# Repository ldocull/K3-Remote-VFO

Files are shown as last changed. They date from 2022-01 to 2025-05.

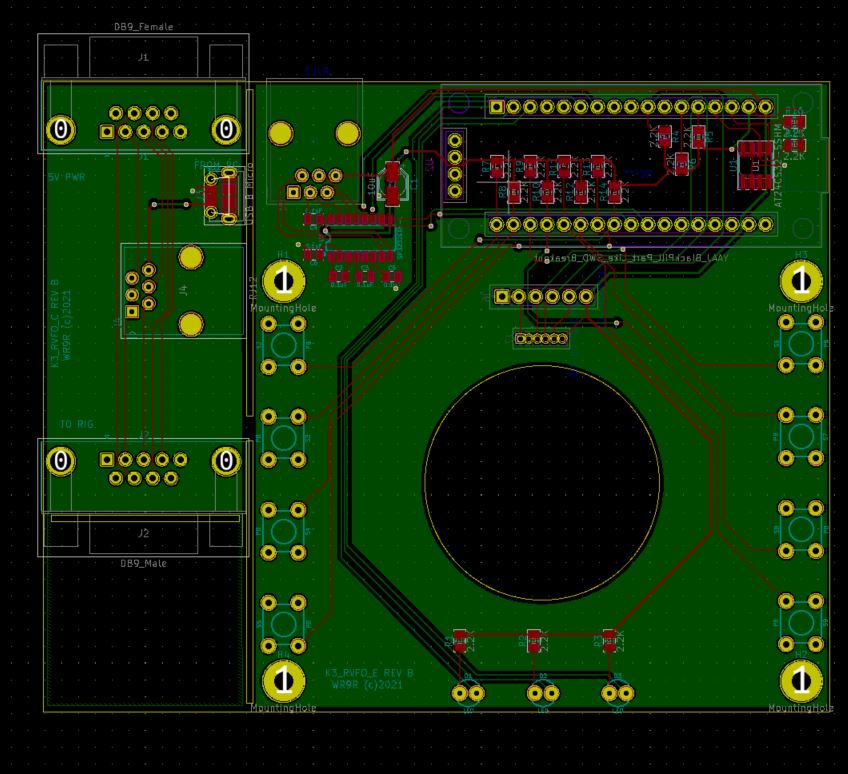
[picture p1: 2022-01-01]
PCBtop.JPG

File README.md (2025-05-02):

# K3-Remote-VFO
Remote VFO and Button Interface for Elecraft, Kenwood and other radio transceivers

## Introduction
The system is comprised of two pieces
 - A Remote Controls Unit
 - A Connector Interface to the Rig 
 
Main Remote Control Unit
Connector Interface

The Connector Interface goes between the control PC and the Rig using classic RS-232. This system is not currently set up to support modern USB interfaces. The main Remote control is tethered to the Connector Interface using a RJ12 (6P/6J) straight-through cable.  Power (5VDC) is supplied to the device from a USB port or power supply to the Connector Interface via a micro-USB jack.

## About the Design Data

The Mechanics were designed in Fusion 360, A full step-assembly is in the repo which could be pulled into any modern CAD package for alteration.   

The construction is plastic. The case frame was FDM printed from PLA, and the top/bottom were laser cut from 
0.08" acrylic. The main-dial and keycaps were SLA (resin) printed on an [Elegoo Mars](https://www.elegoo.com/collections/3d-printing/products/elegoo-mars-3-lcd-3d-printer) printer.

The Electronics were designed in KiCAD. KiCAD is free and easy to use, so this should be a good start for further work. I used [JLCPCB](https://jlcpcb.com/) to manufacture the PCBs.

PCB Setup

The Software is Arduino-based and runs on a [STM32F103C8 BlackPill](https://hobbycomponents.com/st-micro-electronics/960-stm32f103-black-pill-development-board). The project is in Visual Studio Code, and PlatformIO which are currently both free tools.  The Maple bootloader was installed to make the development quick and easy and is included in the repo.

## Updating Encoder and Key Definitions

The keys are assigned text-macros which are stored in non-volatile memory on the Remote unit. The encoder-wheel is handled the same way. The wheel can be pressed and therefore the operation has been divided into four "speeds" (as is indicated by the LEDs below the wheel.)  In the case of the encoder, the macros are also divided into four sets up ***"up"*** and ***"down"*** movements and the text contents are transmitted on each pulse of the wheel.

The default baud rate is ***38400*** and the Remote can be updated in-situ using a terminal emulator such as [RealTerm](https://realterm.sourceforge.io/).   

The following text could be uploaded to the remote.  `'$$$'` is used to mark the beginning of the upload, and `'&&&'` is used to end the upload.  Note that the macros are defined as ```<Kx> text message </K>'``` and `<Ex> text message </E>`. 

> (*Note the messages defined below are for the Elecraft K3.)*

```
$$$			// 3 dollar start of file

<K0>SWT11;</K>  //  A/B  menus stuff here...
<K1>SWT13;</K>  // A->B
<K2>SWT42;</K>  // SPOT

<K3>SWT29;</K>  // XFILT

<K4>SWT21;</K>  // M1-M2
<K5>SWT31;</K>  
<K6>SWT35;</K>  
<K7>SWT39;</K>  

<E0>UP4;</E>    // encoder modes here 0-3, increment/decrement
<E1>DN4;</E>    

<E2>UP8;</E>    
<E3>DN8;</E>    

<E4>UP1;</E>    
<E5>DN1;</E>    

<E6>UP0;</E>    
<E7>DN0;</E>	// end of file is ampersand

&&&
```

### Enjoy, 73,  de WR9R

___
Let us know that this work has been helpful to you.  Any proceeds will be used to offset expenses and further the art. 


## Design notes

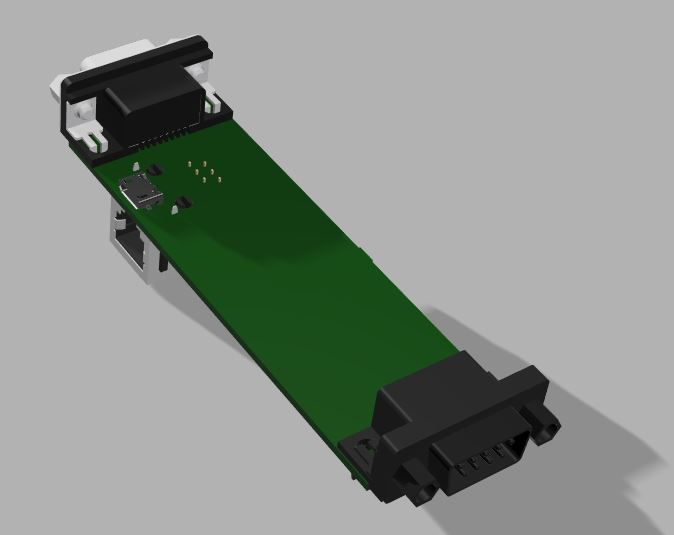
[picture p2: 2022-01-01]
Connector.JPG

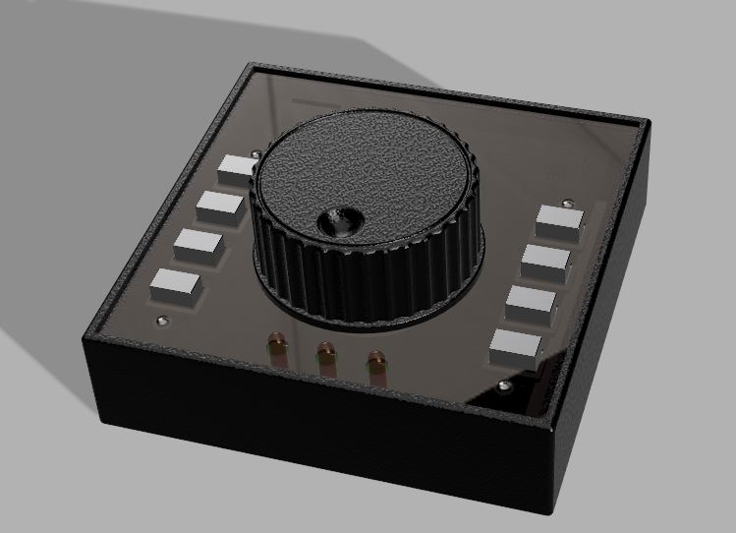
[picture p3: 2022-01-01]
Remote.JPG

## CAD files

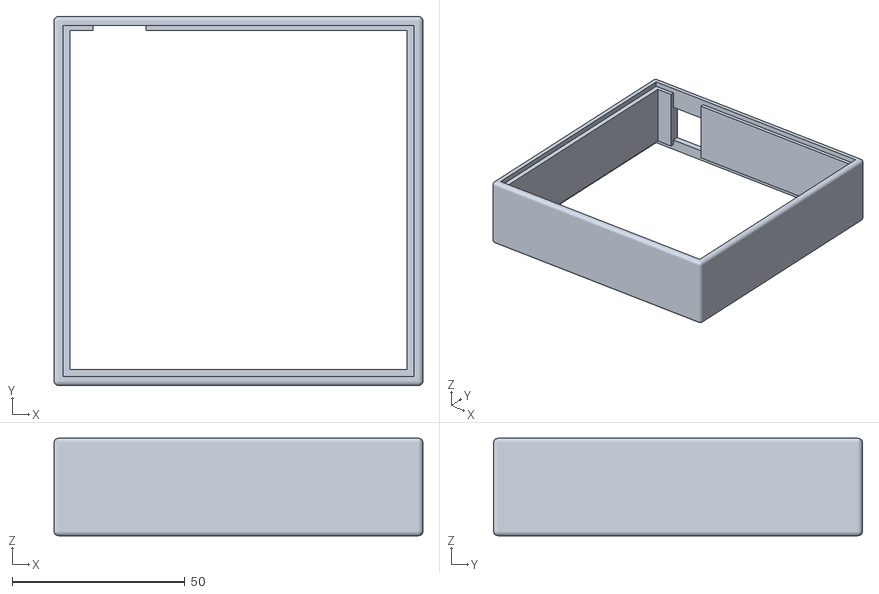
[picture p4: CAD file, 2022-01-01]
3D_Print_Files/Frame.stl
106.7 x 106.7 x 28.2

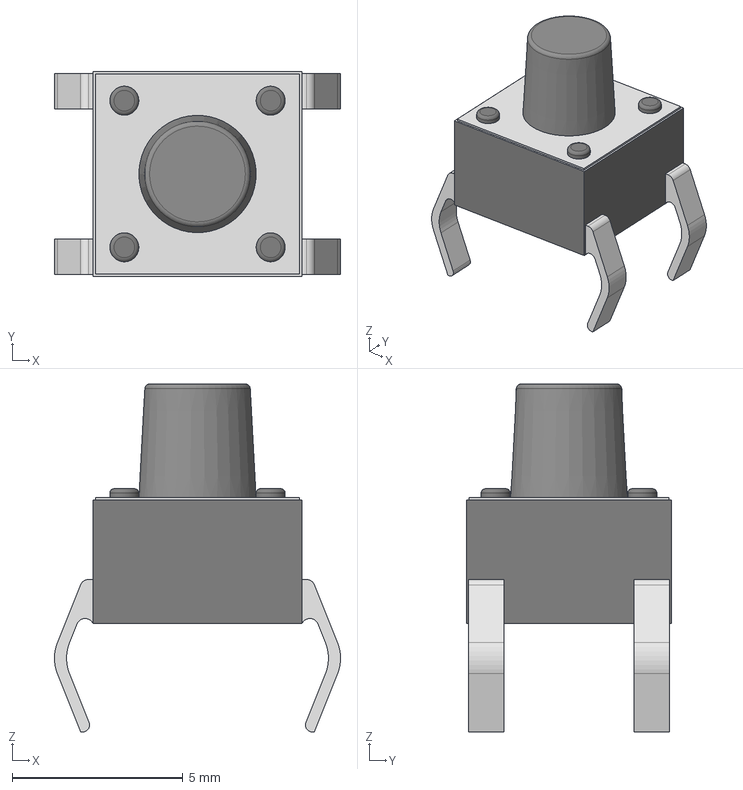
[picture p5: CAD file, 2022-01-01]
Electrical/K3_RVFO-KiCAD/Tactal Switch -Thru (6mmx 6mmx7.0mm).stp
8.37 x 5.99 x 10.2 mm

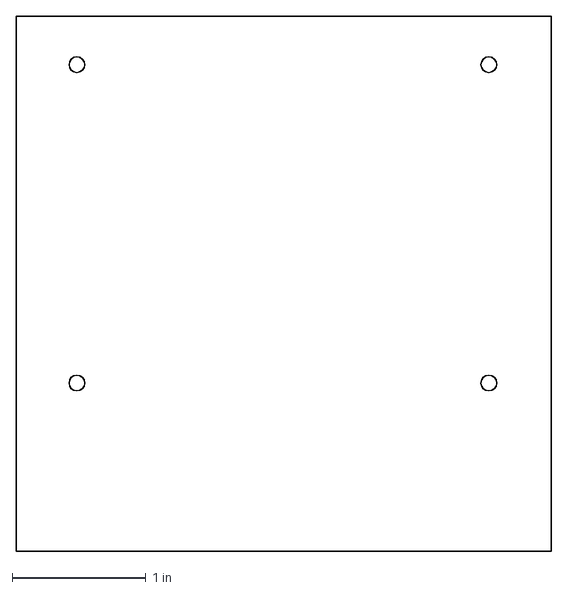
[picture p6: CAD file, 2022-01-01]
Laser_Cut_Files/BackPlate.dxf
4.00 x 4.00 in

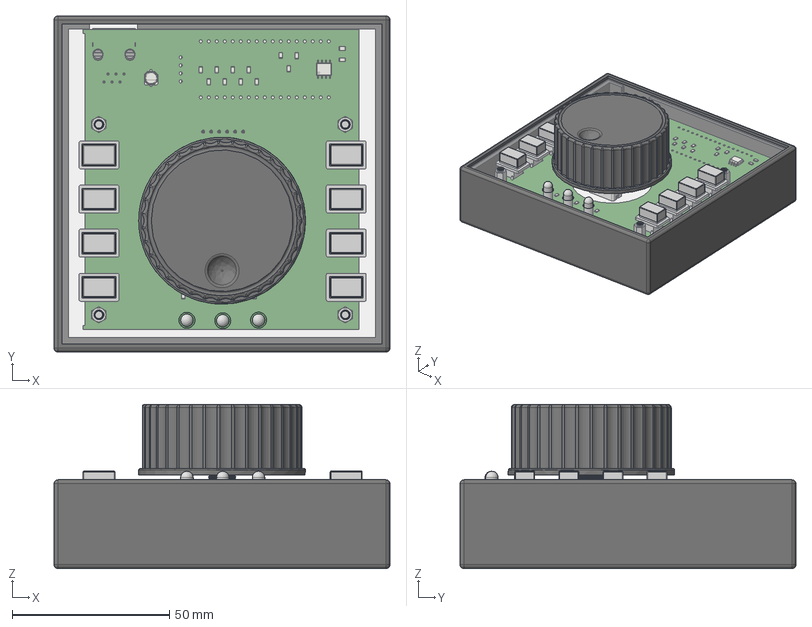
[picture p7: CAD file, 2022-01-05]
Mechanical/FreeCAD/WR9R_K3_VFO.FCStd
106.7 x 106.7 x 52.1 mm
LED
LED001
LED002
c-5555140-1-e-3d v1
KeyCap v3
Tactal Switch -Thru (6mmx 6mmx7.0mm) v1
Tactal Switch -Thru (6mmx 6mmx7.0mm) v002
KeyCap v004
Tactal Switch -Thru (6mmx 6mmx7.0mm) v003
KeyCap v005
Tactal Switch -Thru (6mmx 6mmx7.0mm) v004
KeyCap v006
KeyCap v007
Tactal Switch -Thru (6mmx 6mmx7.0mm) v005
KeyCap v008
Tactal Switch -Thru (6mmx 6mmx7.0mm) v006
Tactal Switch -Thru (6mmx 6mmx7.0mm) v007
KeyCap v009
Tactal Switch -Thru (6mmx 6mmx7.0mm) v008
KeyCap v010
NT1Knob v5
CUI_DEVICES_C14N32P-C3 v1
93655A005_Male-Female Threaded Hex Standoff
92080A012_Zinc-Plated Brass Female Threaded Hex Standoff
92080A012_Zinc-Plated Brass Female Threaded Hex Standoff001
93655A005_Male-Female Threaded Hex Standoff001
93655A005_Male-Female Threaded Hex Standoff002
93655A005_Male-Female Threaded Hex Standoff003
92080A012_Zinc-Plated Brass Female Threaded Hex Standoff002
92080A012_Zinc-Plated Brass Female Threaded Hex Standoff003
FacePlate
BackPlate
Frame

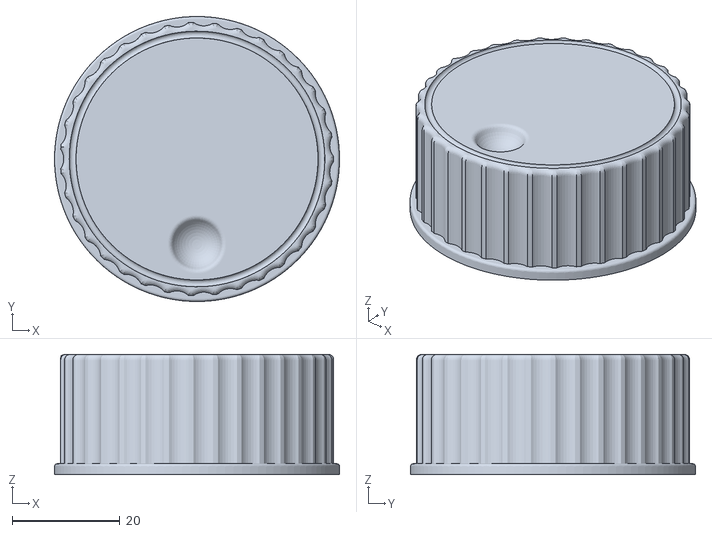
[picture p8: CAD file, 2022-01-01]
3D_Print_Files/Dial.stl
53.0 x 53.0 x 22.4

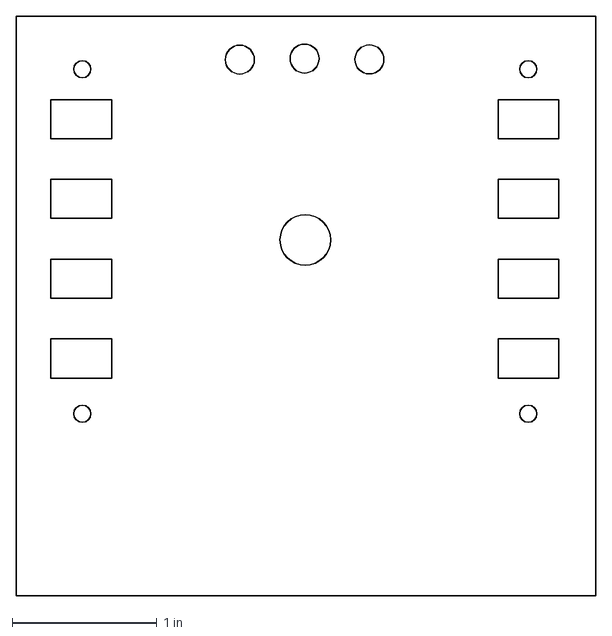
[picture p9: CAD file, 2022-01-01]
Laser_Cut_Files/FacePlate.dxf
4.00 x 4.00 in

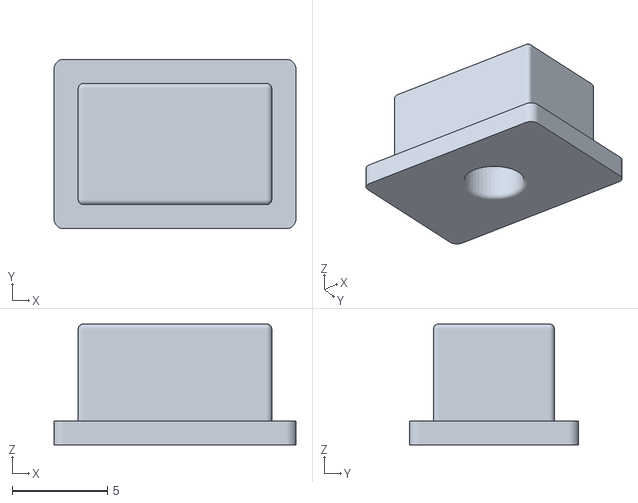
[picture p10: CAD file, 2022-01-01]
3D_Print_Files/ButtonCap.stl
12.7 x 8.89 x 6.35

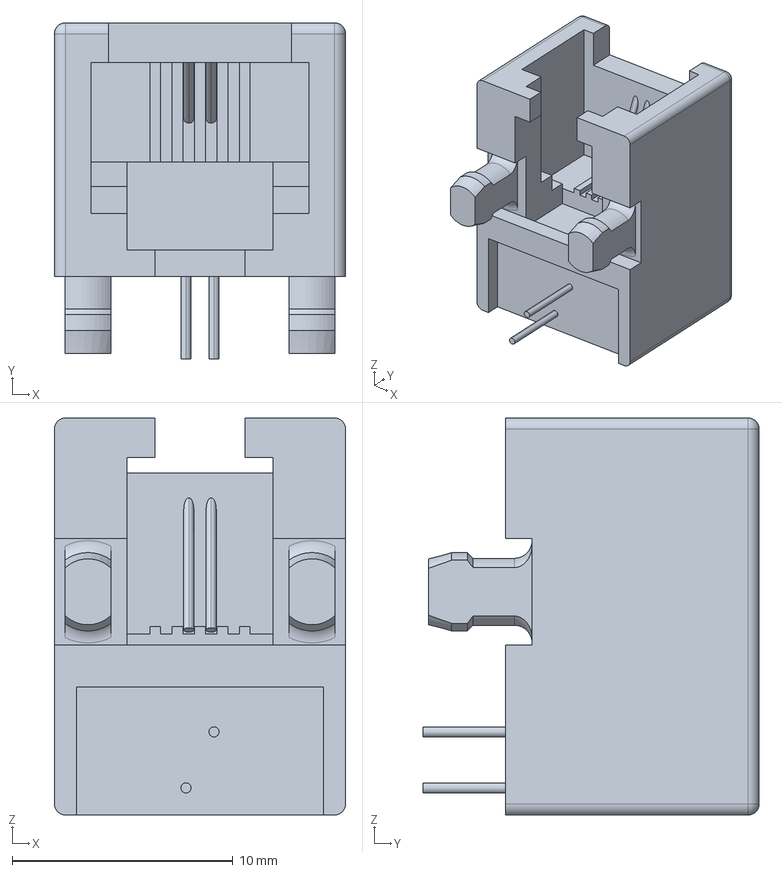
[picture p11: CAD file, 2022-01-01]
Electrical/K3_RVFO-KiCAD/54601-906001WPLFc.stp
13.2 x 15.2 x 18.0 mm

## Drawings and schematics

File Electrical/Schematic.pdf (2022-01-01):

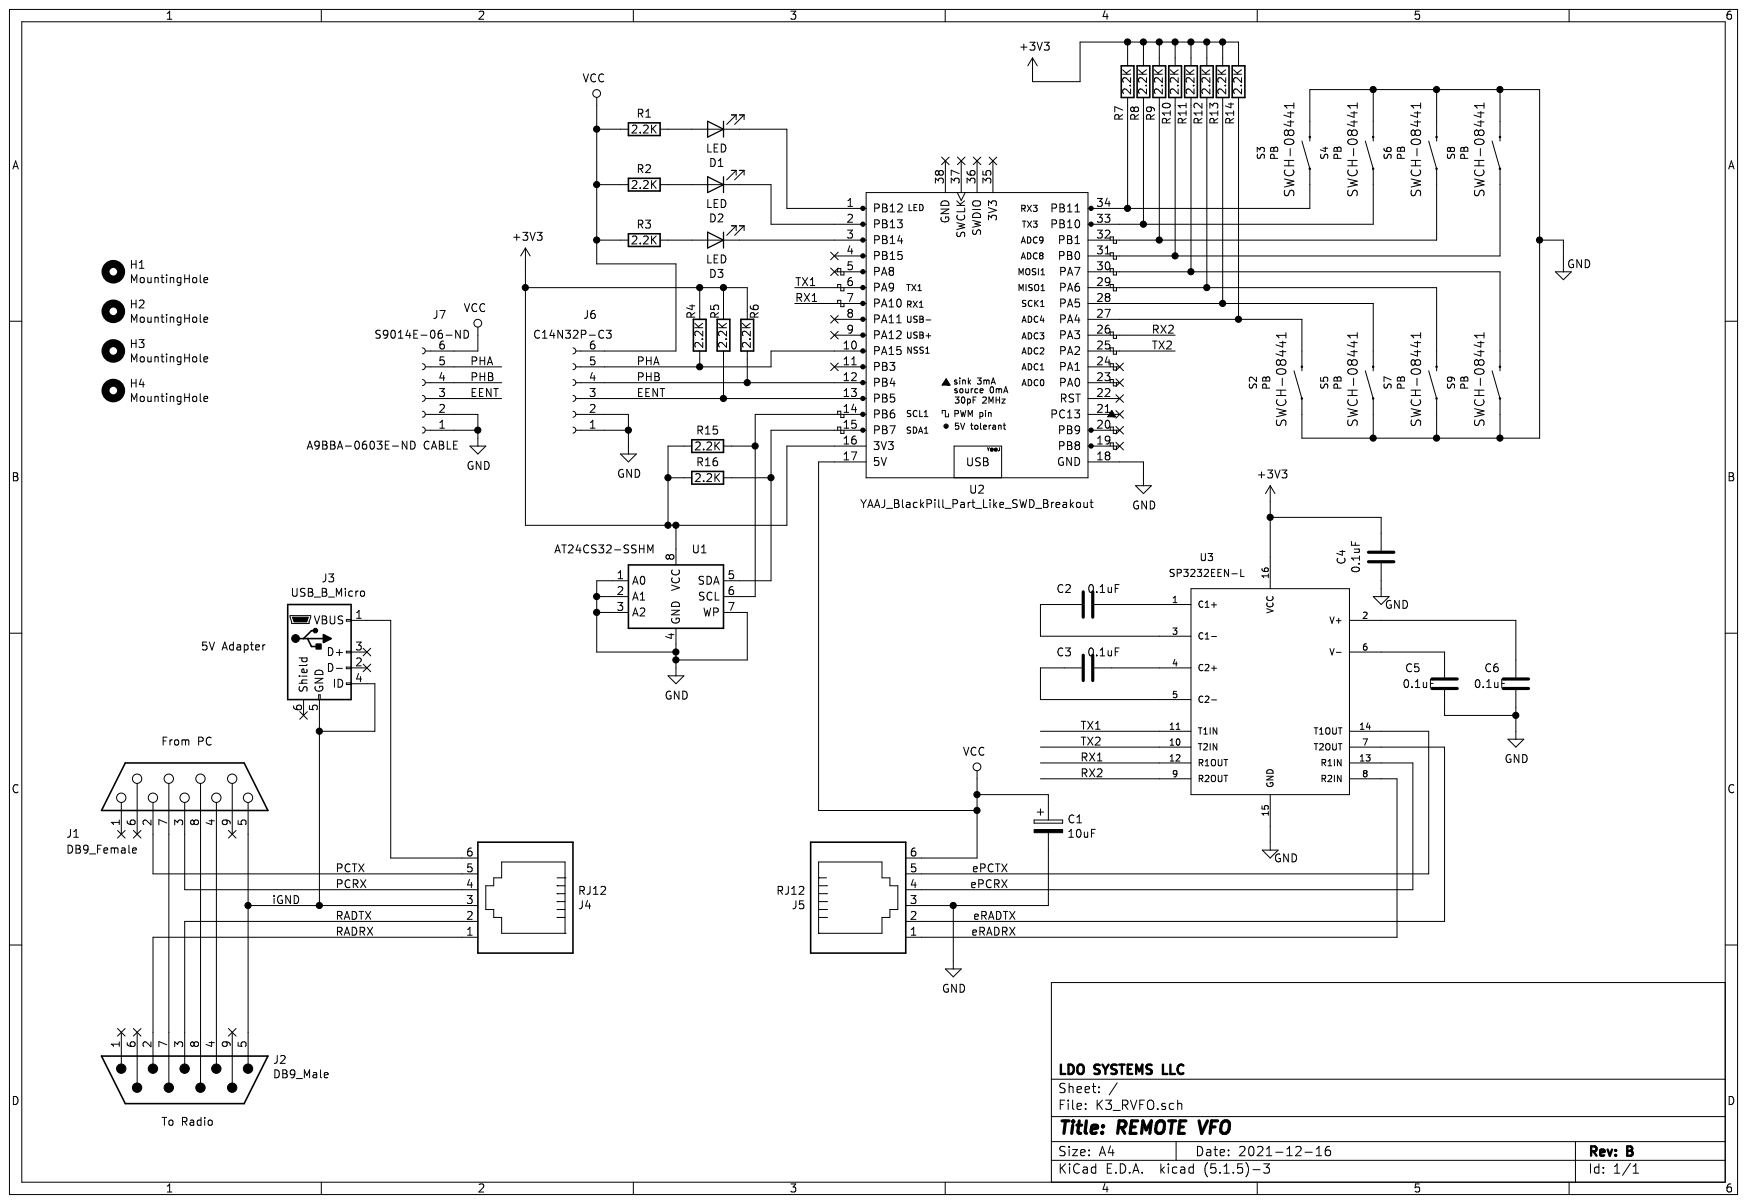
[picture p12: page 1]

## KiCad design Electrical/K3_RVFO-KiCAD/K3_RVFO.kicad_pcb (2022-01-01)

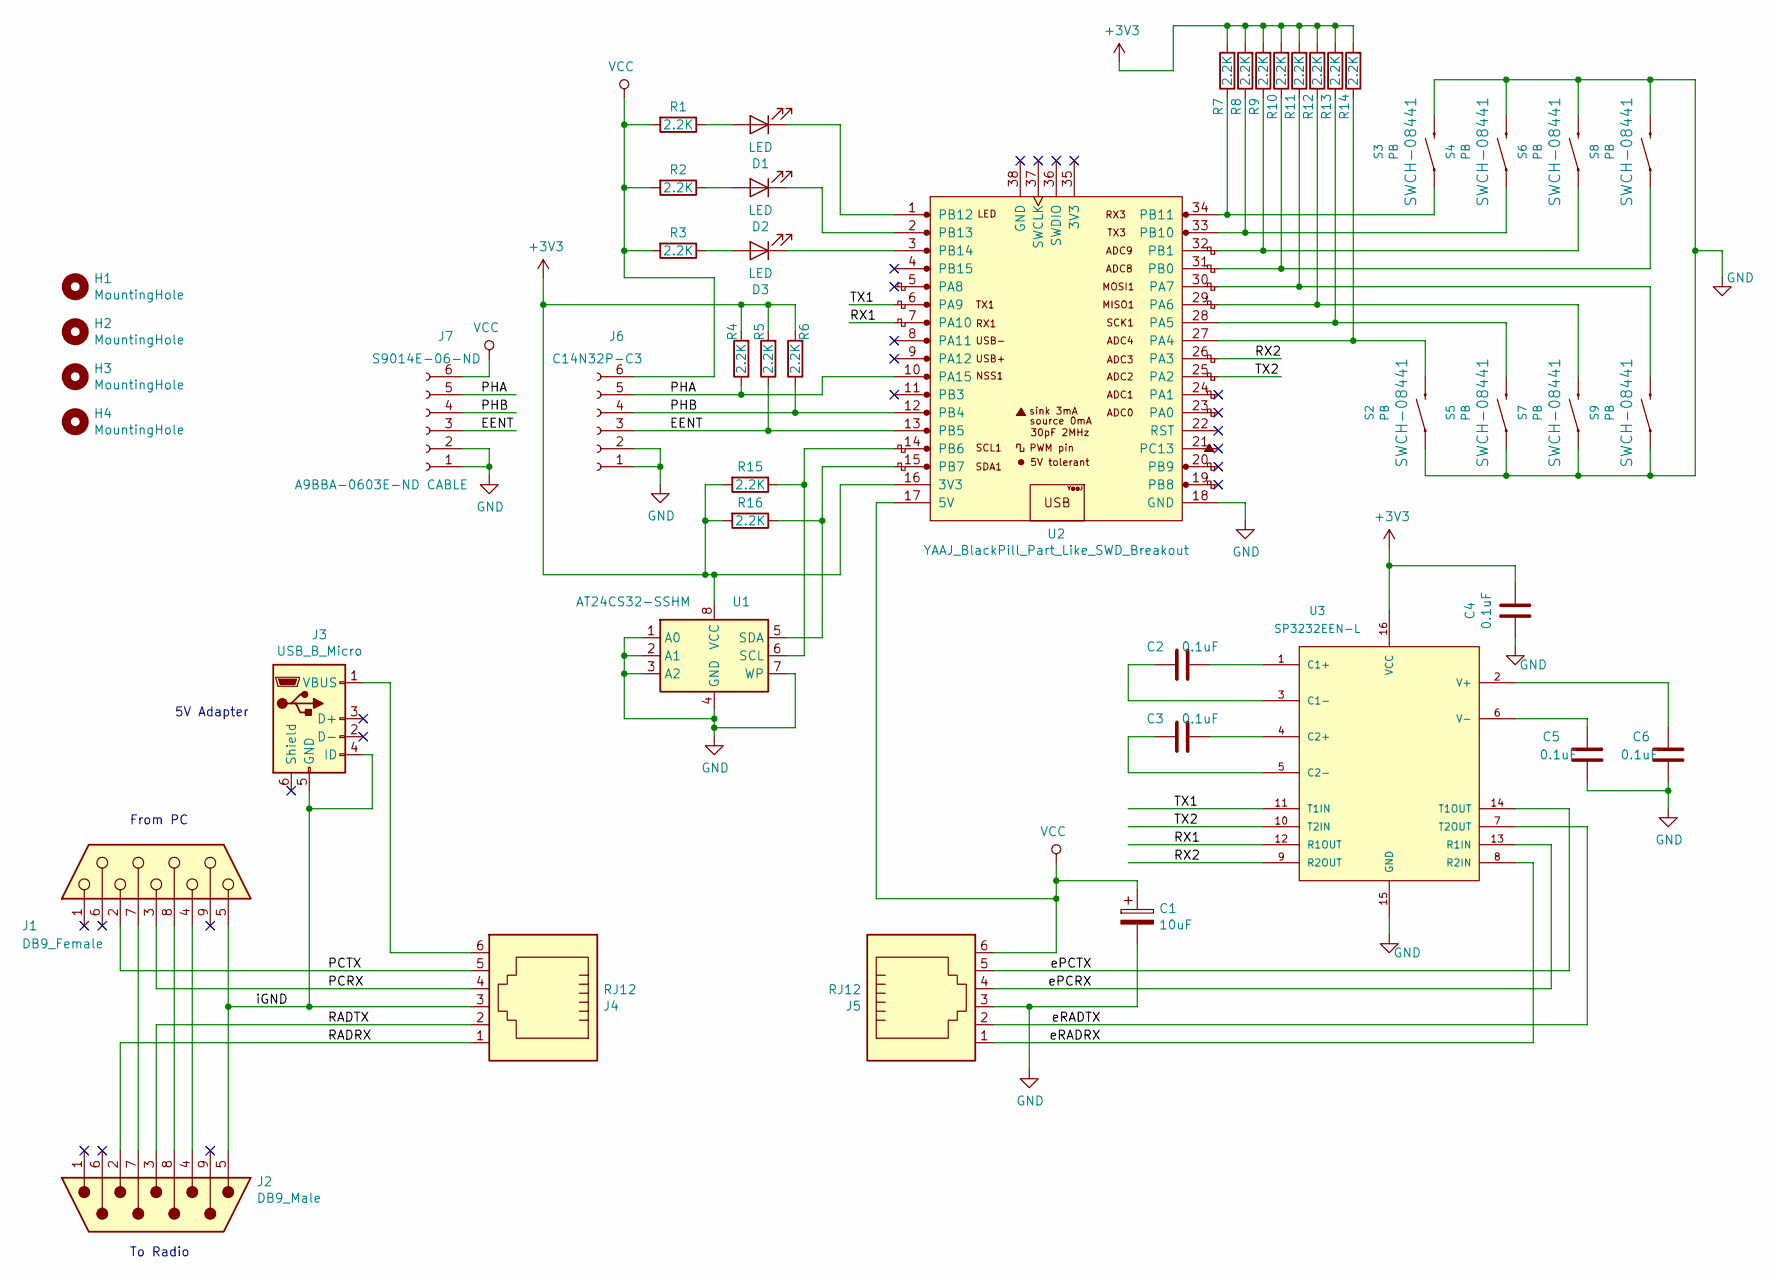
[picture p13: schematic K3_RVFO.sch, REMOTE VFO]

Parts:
C1: 10uF; CP_Elec_4x5.7; JLCPCB C59932
C2, C3, C4, C5, C6: 0.1uF; 0805; JLCPCB C2594299
D1, D2, D3: LED; LED_3MM
H1, H2, H3, H4: MountingHole; MountingHole_3mm_Pad
J1: DB9_Female; DSUB-9_Female_Horizontal_P2.77x2.84mm_EdgePinOffset4.94mm_H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
J2: DB9_Male; DSUB-9_Male_Horizontal_P2.77x2.84mm_EdgePinOffset4.94mm_Hou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
J3: USB_B_Micro; USB_Micro-B_Molex-105017-0001; JLCPCB C10418
J4, J5: RJ12; RJ12_Amphenol_54601
J6: C14N32P-C3; PinHeader_1x06_P2.54mm_Vertical
J7: S9014E-06-ND; PinHeader_1x06_P1.27mm_Vertical
R1, R2, R3, R4, R5, R6, R7, R8, R9, R10, R11, R12, R13, R14, R15, R16: 2.2K; R_0805_2012Metric; JLCPCB C17520
S2, S3, S4, S5, S6, S7, S8, S9: PB; TACTILE_SWITCH_PTH_6.0MM
U1: AT24CS32-SSHM; SOIC-8_3.9x4.9mm_P1.27mm
U2: YAAJ_BlackPill_Part_Like_SWD_Breakout; YAAJ_BlackPill_SWD_2
U3: SP3232EEN-L; SO16; JLCPCB C9378

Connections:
+3V3: C4.1, R4.2, R5.2, R6.2, R7.2, R8.2, R9.2, R10.2, R11.2, R12.2, R13.2, R14.2, R15.2, R16.2, U1.8 (VCC), U2.16 (3V3), U3.16 (VCC)
/EENT: J6.3, J7.3, R5.1, U2.13 (PB5)
/PCRX: J1.3, J4.4
/PCTX: J1.2, J4.5
/PHA: J6.5, J7.5, R4.1, U2.10 (PA15)
/PHB: J6.4, J7.4, R6.1, U2.12 (PB4)
/RADRX: J2.2, J4.1
/RADTX: J2.3, J4.2
/RX1: U2.7 (PA10), U3.12 (R1OUT)
/RX2: U2.26 (PA3), U3.9 (R2OUT)
/TX1: U2.6 (PA9), U3.11 (T1IN)
/TX2: U2.25 (PA2), U3.10 (T2IN)
/ePCRX: J5.4, U3.13 (R1IN)
/ePCTX: J5.5, U3.14 (T1OUT)
/eRADRX: J5.1, U3.8 (R2IN)
/eRADTX: J5.2, U3.7 (T2OUT)
/iGND: J1.5, J2.5, J3.4 (ID), J3.5 (GND), J4.3
GND: C1.2, C4.2, C5.2, C6.2, J5.3, J6.1, J6.2, J7.1, J7.2, S2.1, S3.3 (2), S4.3 (2), S5.1, S6.3 (2), S7.1, S8.3 (2), S9.1, U1.1 (A0), U1.2 (A1), U1.3 (A2), U1.4 (GND), U1.7 (WP), U2.18 (GND), U3.15 (GND)
unnamed: C2.1, U3.1 (C1+)
unnamed: C2.2, U3.3 (C1-)
unnamed: C3.1, U3.4 (C2+)
unnamed: C3.2, U3.5 (C2-)
unnamed: C5.1, U3.6 (V-)
unnamed: C6.1, U3.2 (V+)
unnamed: D1.1 (K), U2.1 (PB12)
unnamed: D1.2 (A), R1.1
unnamed: D2.1 (K), U2.2 (PB13)
unnamed: D2.2 (A), R2.1
unnamed: D3.1 (K), U2.3 (PB14)
unnamed: D3.2 (A), R3.1
unnamed: J1.4, J2.4
unnamed: J1.7, J2.7
unnamed: J1.8, J2.8
unnamed: J3.1 (VBUS), J4.6
unnamed: R7.1, S3.1, U2.34 (PB11)
unnamed: R8.1, S4.1, U2.33 (PB10)
unnamed: R9.1, S6.1, U2.32 (PB1)
unnamed: R10.1, S8.1, U2.31 (PB0)
unnamed: R11.1, S9.3 (2), U2.30 (PA7)
unnamed: R12.1, S7.3 (2), U2.29 (PA6)
unnamed: R13.1, S5.3 (2), U2.28 (PA5)
unnamed: R14.1, S2.3 (2), U2.27 (PA4)
unnamed: R15.1, U1.6 (SCL), U2.14 (PB6)
unnamed: R16.1, U1.5 (SDA), U2.15 (PB7)
VCC: C1.1, J5.6, J6.6, J7.6, R1.2, R2.2, R3.2, U2.17 (5V)

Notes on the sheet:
5V Adapter
From PC
To Radio

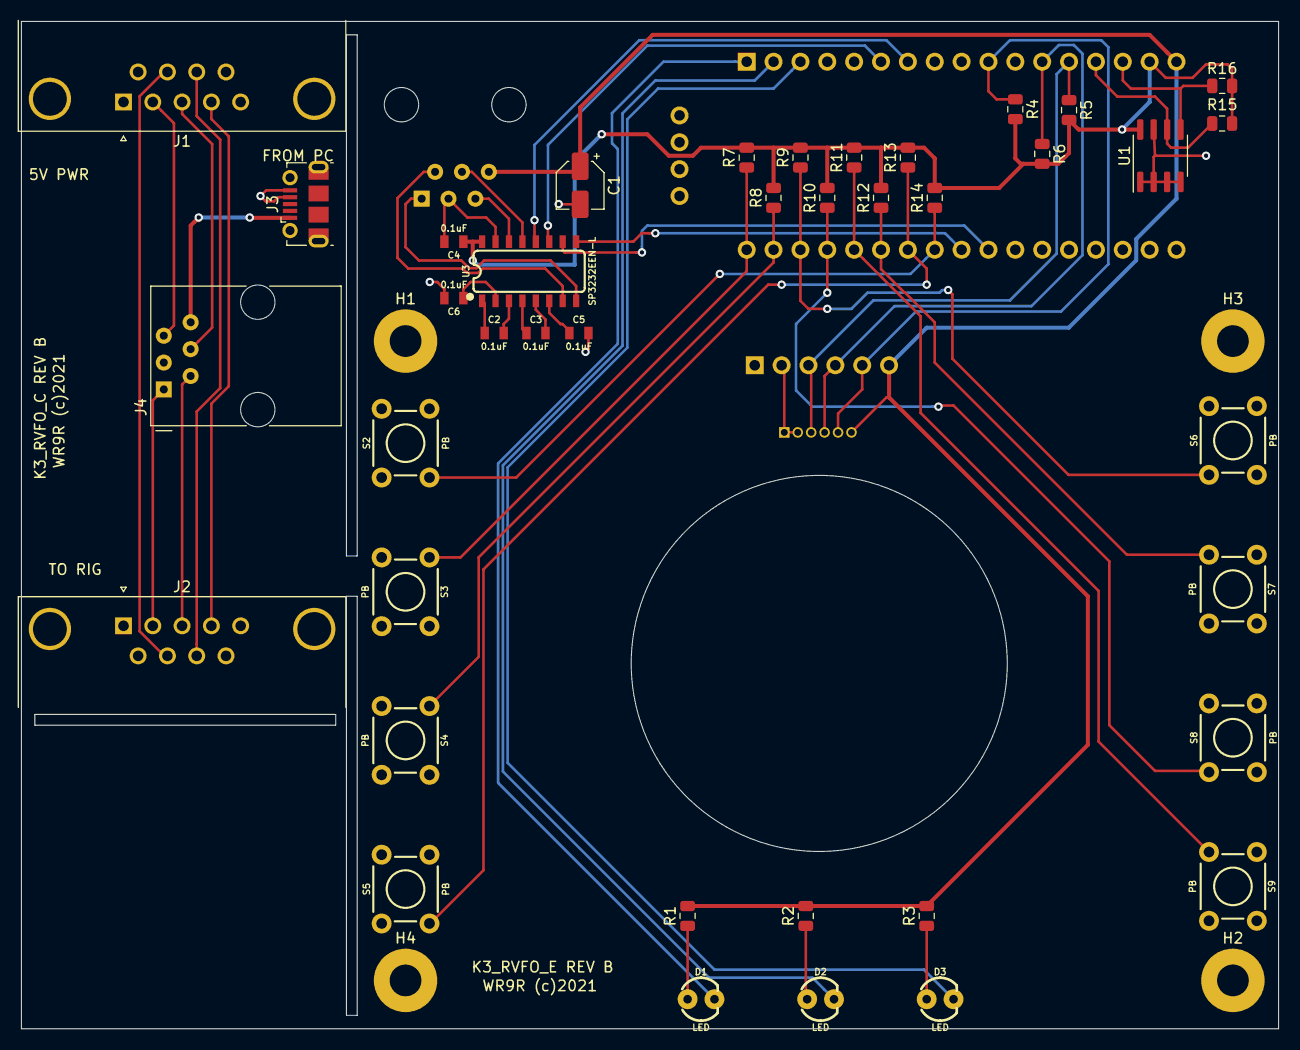
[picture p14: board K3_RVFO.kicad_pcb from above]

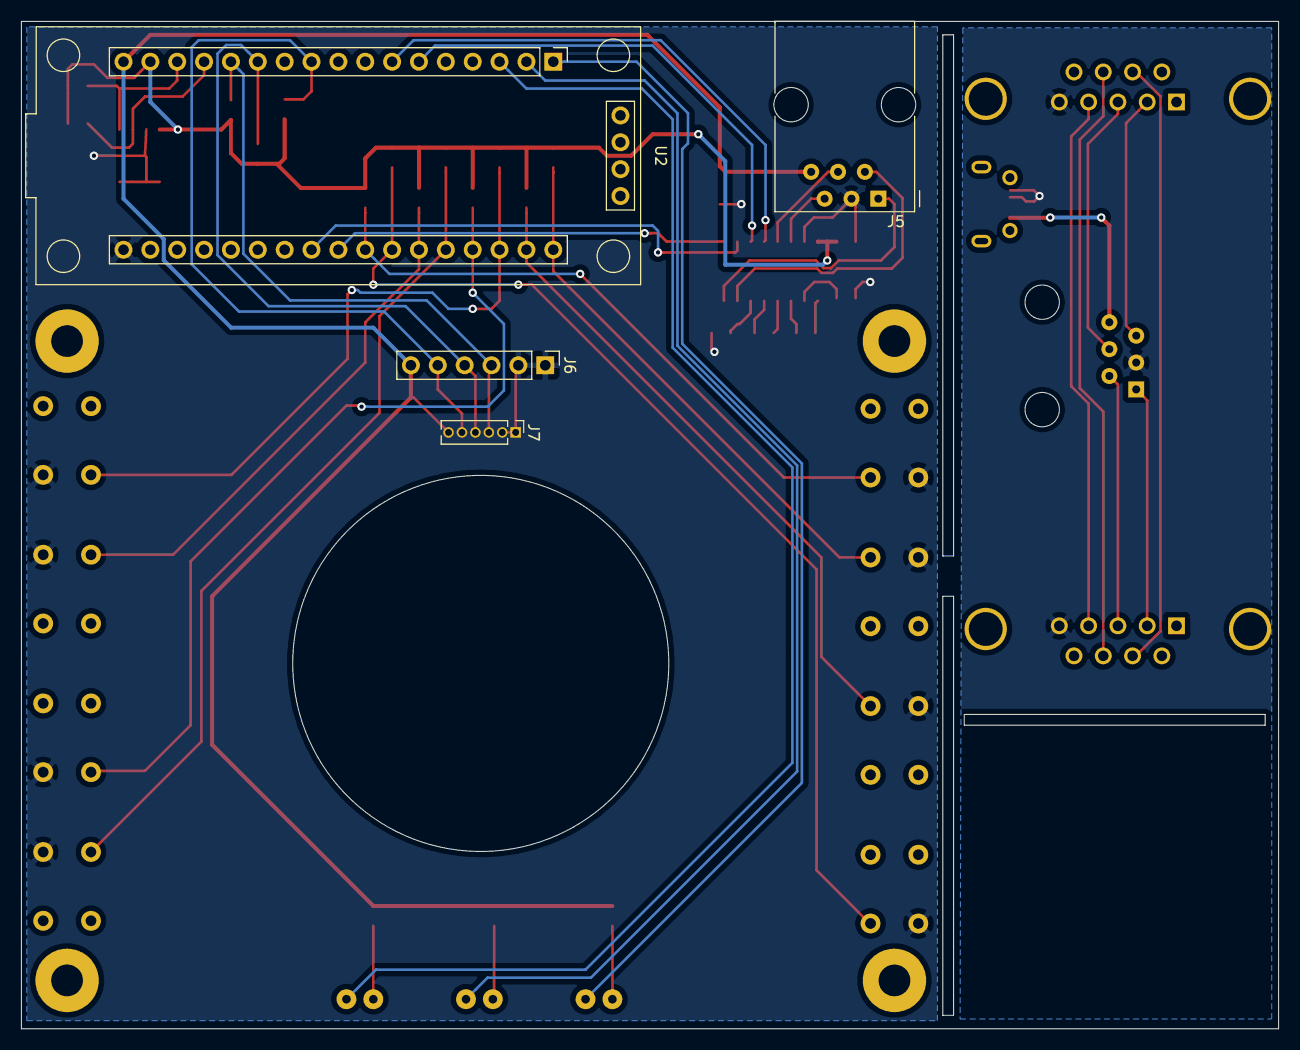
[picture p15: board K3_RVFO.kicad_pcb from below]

Board: 2 copper layers, 118.9 x 95.3 mm, 47 parts (4 on the bottom side), 45 nets.

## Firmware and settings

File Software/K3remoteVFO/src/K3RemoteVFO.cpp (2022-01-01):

/*
  K3 REMOTE VFO

  2021/12/22
  (c)WR9R  Larry O'Cull 2021  LDO Systems LLC
 */

#include <Arduino.h>
#include "wheel.h"
#include "EE24C32.h"

EE24C32 EEPROM(0x50);
USBSerial COMM_PORT;

#define PC_LINK Serial1
#define RIG_LINK Serial2
#define HOST_SIDE PC_LINK
//#define HOST_SIDE COMM_PORT  // -- for using USB port for configuration

#define KEY0  PA4
#define KEY1  PB11
#define KEY2  PB10
#define KEY3  PA5
#define KEY4  PB1
#define KEY5  PA6
#define KEY6  PB0
#define KEY7  PA7
#define ENTER PB5

#define LED0  PB12
#define LED1  PB13
#define LED2  PB14

#define MAX_WHEEL_MODE 3
#define MAX_MESSAGE_INDEX 8
#define MAX_ENCMES_INDEX 8
#define MAX_MESSAGE_SIZE 128

struct EPROM_PLAN 
{
    uint8_t checkValue = 0x14;
    
    char keyMessage[MAX_MESSAGE_INDEX][MAX_MESSAGE_SIZE] = {
        {"SWT09;"},   // BAND +
        {"SWT10;"},   // BAMD -
        {"SWT17;"},   // MODE ++
        {"SWT29;"},   // XFIL
        {"SWT21;"},   // M1-M4...
        {"SWT31;"},
        {"SWT35;"},
        {"SWT39;"}};
    
    char encMessage[MAX_MESSAGE_INDEX][MAX_MESSAGE_SIZE] = {
        {"UP0;"},    // encoder base
        {"DN0;"},
        {"UP1;"},    // encoder up 1 level
        {"DN1;"},
        {"UP8;"},    // encoder up 2nd level
        {"DN8;"},
        {"UP4;"},    // encoder up 3nd level
        {"DN4;"}};

    int wheelMode = 0;

} rigSettings, backupSettings;

int initialized = 0;

// the setup function runs once when you press reset or power the board
void setup() {
  // initialize digital pin PB1 as an output.
  pinMode(LED0, OUTPUT);
  pinMode(LED1, OUTPUT);
  pinMode(LED2, OUTPUT);

  pinMode(KEY0,INPUT_PULLUP);
  pinMode(KEY1,INPUT_PULLUP);
  pinMode(KEY2,INPUT_PULLUP);
  pinMode(KEY3,INPUT_PULLUP);
  pinMode(KEY4,INPUT_PULLUP);
  pinMode(KEY5,INPUT_PULLUP);
  pinMode(KEY6,INPUT_PULLUP);
  pinMode(KEY7,INPUT_PULLUP);
  pinMode(ENTER,INPUT_PULLUP);

  PC_LINK.begin(38400); // PC side of life..  

  pinMode(PA3,INPUT_PULLUP);
  pinMode(PA2,OUTPUT);
  RIG_LINK.begin(38400); // Rig side of life..
  init_Encoder();
   COMM_PORT.begin(115200);
}

// lists the values of the stored message/macros for keys and encoder
void printMacros()
{
    int i;
      
    for(i=0; i< MAX_MESSAGE_INDEX; i++)
    {
      HOST_SIDE.print("<K");
      HOST_SIDE.print(i);
      HOST_SIDE.print(">");
      HOST_SIDE.print(rigSettings.keyMessage[i]);
      HOST_SIDE.println("</K>");
    }

    for(i=0; i< MAX_ENCMES_INDEX; i++)
    {
      HOST_SIDE.print("<E");
      HOST_SIDE.print(i);
      HOST_SIDE.print(">");
      HOST_SIDE.print(rigSettings.encMessage[i]);
      HOST_SIDE.println("</E>");
    }
}

// returns a key value 1-8 (9 for main dial), 0 if none pressed
int getKeyPress()
{
  if(!digitalRead(KEY0)) return 1;
  if(!digitalRead(KEY1)) return 2;
  if(!digitalRead(KEY2)) return 3;
  if(!digitalRead(KEY3)) return 4;
  if(!digitalRead(KEY4)) return 5;
  if(!digitalRead(KEY5)) return 6;
  if(!digitalRead(KEY6)) return 7;
  if(!digitalRead(KEY7)) return 8;
  if(!digitalRead(ENTER)) return 9;
  return 0;
}

// set LEDs based on lower 3-bits of 'n'
void setLEDs(int n)
{
  digitalWrite(LED0,HIGH);
  digitalWrite(LED1,HIGH);
  digitalWrite(LED2,HIGH);

  if(n & 1)
      digitalWrite(LED0,LOW);
  if(n & 2)
      digitalWrite(LED1,LOW);
  if(n & 4)
      digitalWrite(LED2,LOW);
}

void saveRigSettings(int force)
{
    uint8_t *rp, *bp;

    rp = (uint8_t *)&rigSettings;
    bp = (uint8_t *)&backupSettings;       // save any changed memories to EEPROM
    for (int i=0; i < (int) sizeof(rigSettings); i++)
    {
        if((*rp != *bp) || (force != 0))
        {
            EEPROM.write(i, *rp);
            *bp = *rp;
            // chk = 1;
        }    
        bp++;
        rp++;
    }
}

void restoreRigSettings(void)
{
    uint8_t *rp,*bp;

    if(rigSettings.checkValue != EEPROM.read(0))
    {
        saveRigSettings(1); // factory defaults on 1st time on.
    } 
    else
    {
        rp = (uint8_t *)&rigSettings;      // copy EEPROM to rig and backup (comparison) local memory
        bp = (uint8_t *)&backupSettings;
        for (int i=0; i < (int) sizeof(rigSettings); i++)
        {
            *rp = *bp = EEPROM.read(i);
            rp++;
            bp++;
        }   
    }     
}

// blocking read character routine..
char getchBlocking()
{
  char c;
  while(!HOST_SIDE.available()) 
      ;
  c = HOST_SIDE.read();    
  HOST_SIDE.write( c );
  return c;
}  

int engSeqCnt = 0;  // escape sequence counter..

// this routing watches the stream from the PC 
// and if '$$$' is detected, then parses and stores macro definitions
// until '&' is detected.  When '&' arrives, the macros are saved
// to EEPROM and then listed back to the 'console'
void commandProc()
{
    char c, t, *p;
    int i;

    if(!HOST_SIDE.available()) return;
    
    c = HOST_SIDE.peek();
    if(c == '$')
    {
      c = getchBlocking();
      engSeqCnt++;
    }
    else
      engSeqCnt = 0;

    if(engSeqCnt >= 3)
    {
      HOST_SIDE.print('>'); // prompt to indicate terminal mode..
      c = getchBlocking();
      while(1)
      {
        if( c == '?')
        {
          printMacros(); 
        }

        if( c == '&') 
        {
          saveRigSettings(0);
          printMacros();   
          return;
        }

        if( c == '<')
        {
          t = getchBlocking();  // grab K or E
          c = getchBlocking();  // and the index
          i = (int) c - '0';
          getchBlocking();      // eat the carrot..

          HOST_SIDE.print(t);
          HOST_SIDE.print(i);
          HOST_SIDE.println(":");

          if(i < MAX_MESSAGE_INDEX)
          {
            p = &rigSettings.keyMessage[i][0];
            if( t == 'E')
              p = &rigSettings.encMessage[i][0];

            while(1)
            { 
              c = getchBlocking();
              if( c == '<') break;
              *p++ = c;
            }
            *p = 0;  // terminate string...
          }
          getchBlocking();      // eat the slash..
          getchBlocking();      // eat the end mark..
          getchBlocking();      // eat the carrot..
        }
        c =  getchBlocking();   // next char...
      }
    } 
}

// the loop function runs over and over again forever
void loop() 
{
  char c;

  if(!initialized)
  {
    delay(8000);
    COMM_PORT.println("Initialize VFO..");
    // printMacros();    
    delay(1000);
    initialized = 1;
    setLEDs(0);
    COMM_PORT.println("Initialize I2C..");
      
    EEPROM.begin(&Wire);
    int test = EEPROM.read(0x0);
    COMM_PORT.print("EEPROM TEST: ");
    COMM_PORT.println(test, HEX);
    restoreRigSettings();     // get rig state from EEPROM
    
    setLEDs(1<<rigSettings.wheelMode); // restore LEDs to reflect last state
  }

  if(initialized)
  {
    commandProc();

    while(PC_LINK.available() || RIG_LINK.available())
    {
      while(PC_LINK.available())  // exchange left<->right
      { 
        c = PC_LINK.read();
        RIG_LINK.write(c);
      }
      while(RIG_LINK.available())
      {
        c = RIG_LINK.read();
        PC_LINK.write(c);
      }
      delay(20);  // look for opening in communications
    }

    if(getKeyPress() != 0) // look for key presses..
    {
      delay(20);
      if(getKeyPress() != 0)  // debounce on (pressed)
      {
        if(getKeyPress() < 9)     // macro key preses
        {  
          RIG_LINK.print(rigSettings.keyMessage[getKeyPress()-1]);
        }
        else
        {
          rigSettings.wheelMode++;
          if(rigSettings.wheelMode > MAX_WHEEL_MODE)
            rigSettings.wheelMode = 0;
          setLEDs(1<<rigSettings.wheelMode);  // jog-wheel presses
          saveRigSettings(0);                 // save state to EEPROM
        }

        while(getKeyPress() != 0) // debounce off (released)
        delay(20);
      }
    }

    extern int wheelValue, lastWheelValue;

    processWheel();
    if(wheelValue != lastWheelValue)      // send macro message for appropriate mode, for up and down
    {
        if(lastWheelValue > wheelValue)
            RIG_LINK.print(rigSettings.encMessage[rigSettings.wheelMode*2]);
        else
            RIG_LINK.print(rigSettings.encMessage[(rigSettings.wheelMode*2)+1]);

        lastWheelValue = wheelValue;
    }
  }
}

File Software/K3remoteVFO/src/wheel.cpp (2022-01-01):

/*
    Main tuning and navigation wheel management
    (c)WR9R  Larry O'Cull 2021
*/
#include "wheel.h"

int wheelValue = 0, lastWheelValue=0; // changes in knob rotation +/-
int lastiostate = 0, iostate = 0;


void processWheel()
{
  iostate = 0;
  if(digitalRead(Encoder_XA)) iostate |= 1;
  if(digitalRead(Encoder_XB)) iostate |= 2;

  if(iostate == lastiostate) return;

  switch (lastiostate)
  {
    case 3:
      if(iostate == 1)
        wheelValue++;
      else
        wheelValue--;
      break;

    case 2:
      if(iostate == 3)
        wheelValue++;
      else
        wheelValue--;
      break;

    case 0:
      if(iostate == 2)
        wheelValue++;
      else
        wheelValue--;
      break;

    case 1:
      if(iostate == 0)
        wheelValue++;
      else
        wheelValue--;
      break;

    default:
      break;
  }
  lastiostate = iostate;
}

void init_Encoder(void)
{
  pinMode(Encoder_XA, INPUT);
  pinMode(Encoder_XB, INPUT);
  pinMode(Enter_Button, INPUT);
}

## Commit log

2022-01-01 Initial commit 1/1/2022 - WR9R
    [54601-906001WPLFc.stp, BackPlate.dxf, ButtonCap.stl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]
2022-01-01 Added gerbers...
    [K3_RVFO-B_Cu.gbr, K3_RVFO-B_Mask.gbr, K3_RVFO-Edge_Cuts.gbr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]
2022-01-01 Added PDF Schematic
2022-01-05 Adjusted slot width per G6CMV feedback
    [K3_RVFO-B_Cu.gbr, K3_RVFO-B_Mask.gbr, K3_RVFO-Edge_Cuts.gbr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]
2022-01-05 Added zip of the gerbers for ease
2022-01-05 Added zip file of gerbers for ease as well as freeCAD project reference. Updated drill files.
    [WR9R_K3_VFO.FCStd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]

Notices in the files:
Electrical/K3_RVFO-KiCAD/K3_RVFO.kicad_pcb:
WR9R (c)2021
